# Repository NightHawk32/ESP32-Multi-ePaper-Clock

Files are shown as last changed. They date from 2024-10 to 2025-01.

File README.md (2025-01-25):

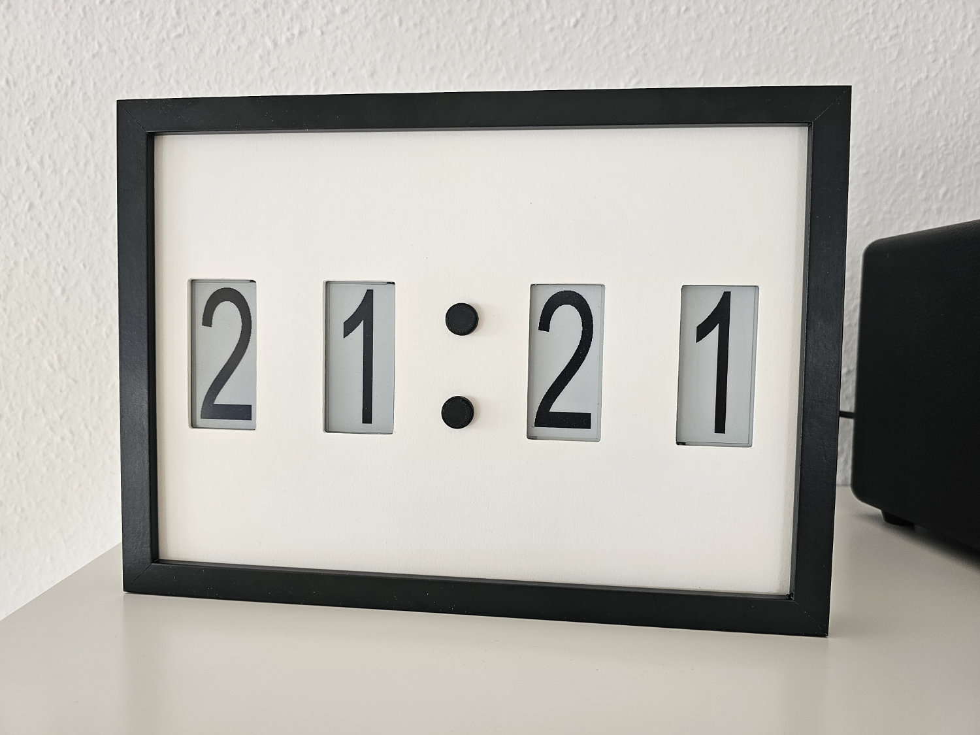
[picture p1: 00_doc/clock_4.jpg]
Clock


# Configuration

create myWifi.h in 01_src\include`` with the following content, containing your wifi credentials:

```cpp
#ifndef MYWIFI_H_
#define MYWIFI_H_

#define MY_WIFI_SSID "<ssid>"
#define MY_WIFI_PASSWORD "<wifi_password>"

#define NTP_SERVER "pool.ntp.org"

#endif
```

# Wiring Diagram
In case you need to change the pinout, the pin definitions are in `01_src\include\board.h`.
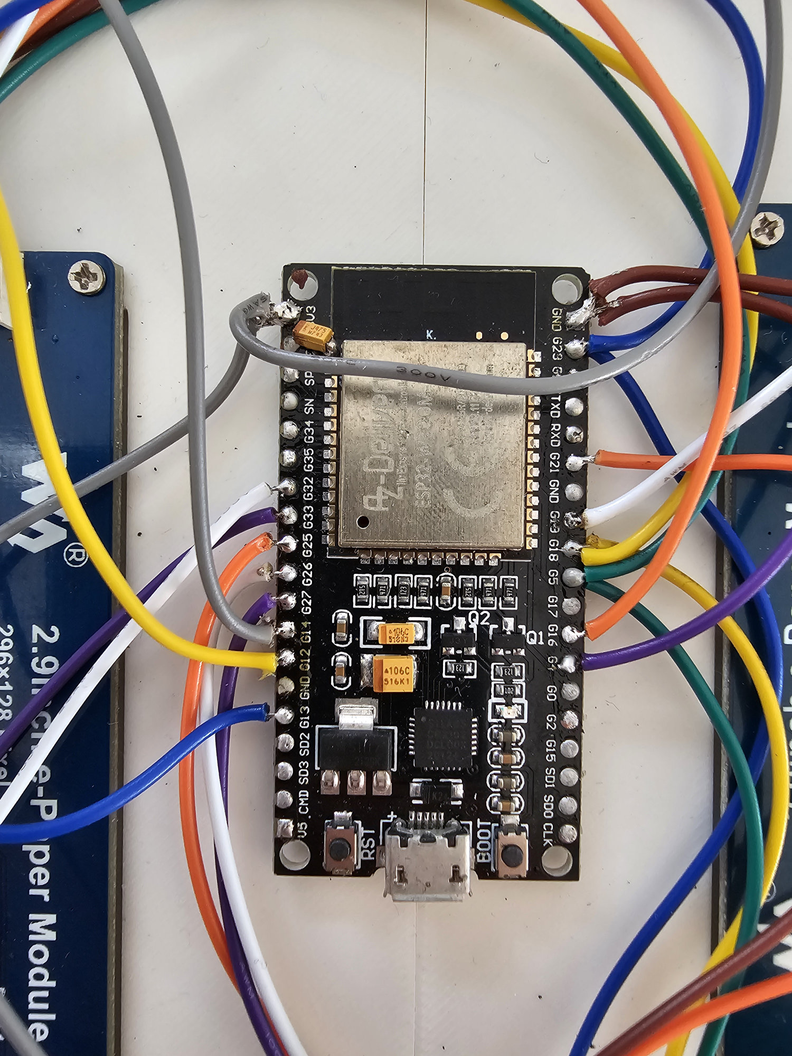
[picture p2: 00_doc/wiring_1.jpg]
Wiring Diagram

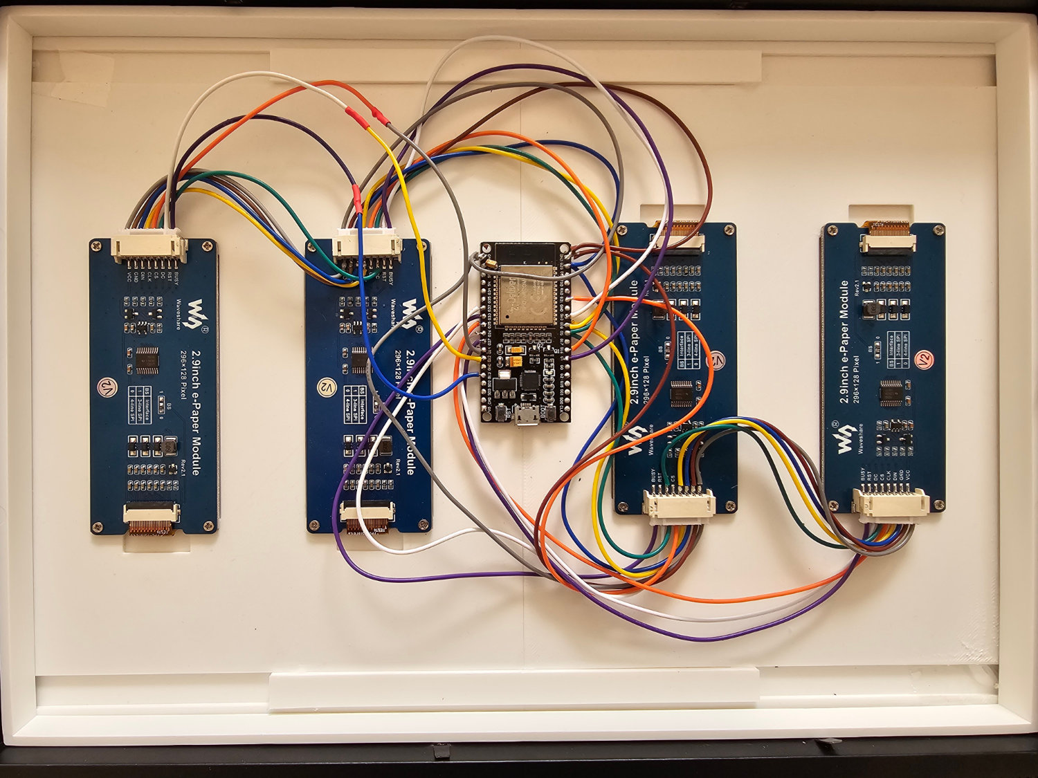
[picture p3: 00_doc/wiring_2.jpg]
Wiring Diagram


# Parts List
- picture frame 30x40 cm ([IKEA RÖDALM](https://www.ikea.com/de/de/p/roedalm-rahmen-schwarz-20548918/))
- ESP32 Dev Kit (e.g. [AZDelivery ESP32 NodeMCU](https://www.az-delivery.de/en/products/esp32-developmentboard))
- 4x Wavesahre 2.9inch e-Paper Display ([Waveshare 2.9inch e-Paper Display](https://www.waveshare.com/wiki/2.9inch_e-Paper_Module))

# 3D Printing

The 3D printing pars are available in the `02_cad` and on [Printables](https://www.printables.com/model/1162687/).

Parts:
- 2x connector (PLA)
- 2x front panel (PLA, white)
- 2x dot (PLA, black)

# Assembly
To hide the small gap between the front panels I used a big sheet of white paper and cut the display holes into it. The paper is then glued to the back of the front panel.

# Editing the Digit Font

The font file as Affinity Designer file is available in the res directory. To convert the exported images to bitmaps you may use this [tool](https://javl.github.io/image2cpp/). Th bitmaps can be found in `01_src\include\bitmaps.h`.

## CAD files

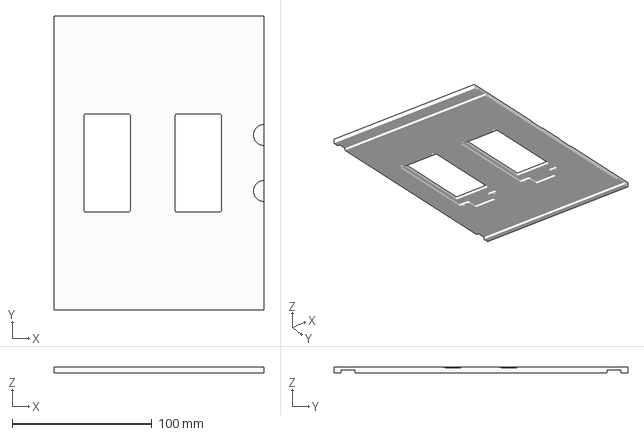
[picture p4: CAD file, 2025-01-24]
02_cad/panel_front.3mf
150.0 x 210.0 x 4.00 mm

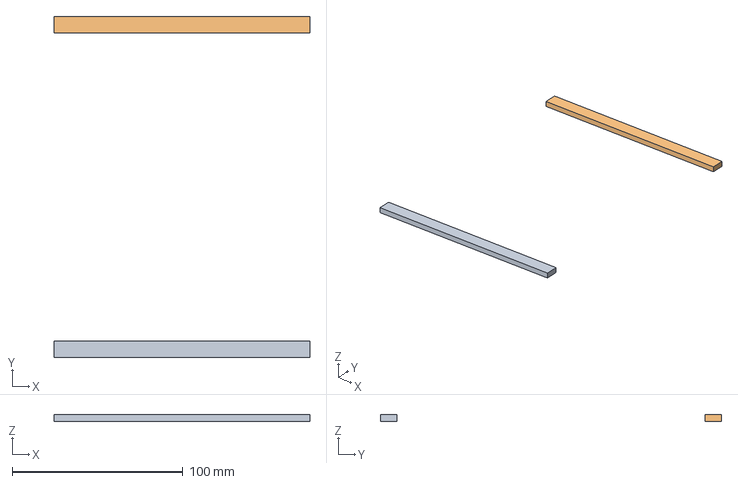
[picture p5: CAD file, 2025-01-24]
02_cad/connector.3mf
149.8 x 199.8 x 4.00 mm
Körper1
Körper2

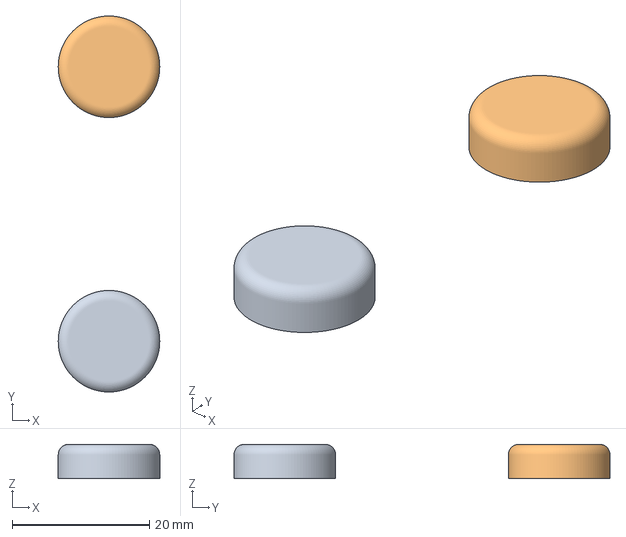
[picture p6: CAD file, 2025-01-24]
02_cad/dot.3mf
14.8 x 54.8 x 5.00 mm
Körper1
Körper2

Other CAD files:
02_cad/29_epaper_4_digit v15.f3z

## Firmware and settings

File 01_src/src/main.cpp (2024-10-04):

#include <GxEPD2_BW.h>
#include "board.h"
#include "bitmaps.h"
#include "GxEPD2_display_selection_new_style.h"
#include <U8g2_for_Adafruit_GFX.h>
#include "myWifi.h"
#include <WiFi.h>
#include <time.h>

const long  gmtOffset_sec = 3600;
const int   daylightOffset_sec = 0;

TaskHandle_t updateDisplayTaskHandle = NULL;
SemaphoreHandle_t semDisplay = NULL;

struct tm timeinfo;

U8G2_FOR_ADAFRUIT_GFX u8g2Fonts1;
U8G2_FOR_ADAFRUIT_GFX u8g2Fonts2;
U8G2_FOR_ADAFRUIT_GFX u8g2Fonts3;
U8G2_FOR_ADAFRUIT_GFX u8g2Fonts4;

const char HelloWorld[] = "Hello World!";
const char one[] = "Hello World!";

void printLocalTime(){
  struct tm timeinfo;
  if(!getLocalTime(&timeinfo)){
    Serial.println("Failed to obtain time");
    return;
  }
  Serial.println(&timeinfo, "%A, %B %d %Y %H:%M:%S");
}

void scanNetworks() {
  Serial.println("Scan start");

  // WiFi.scanNetworks will return the number of networks found.
  int n = WiFi.scanNetworks();
  Serial.println("Scan done");
  if (n == 0) {
      Serial.println("no networks found");
  } else {
      Serial.print(n);
      Serial.println(" networks found");
      Serial.println("Nr | SSID                             | RSSI | CH | Encryption");
      for (int i = 0; i < n; ++i) {
          // Print SSID and RSSI for each network found
          Serial.printf("%2d",i + 1);
          Serial.print(" | ");
          Serial.printf("%-32.32s", WiFi.SSID(i).c_str());
          Serial.print(" | ");
          Serial.printf("%4ld", WiFi.RSSI(i));
          Serial.print(" | ");
          Serial.printf("%2ld", WiFi.channel(i));
          Serial.print(" | ");
          switch (WiFi.encryptionType(i))
          {
          case WIFI_AUTH_OPEN:
              Serial.print("open");
              break;
          case WIFI_AUTH_WEP:
              Serial.print("WEP");
              break;
          case WIFI_AUTH_WPA_PSK:
              Serial.print("WPA");
              break;
          case WIFI_AUTH_WPA2_PSK:
              Serial.print("WPA2");
              break;
          case WIFI_AUTH_WPA_WPA2_PSK:
              Serial.print("WPA+WPA2");
              break;
          case WIFI_AUTH_WPA2_ENTERPRISE:
              Serial.print("WPA2-EAP");
              break;
          case WIFI_AUTH_WPA3_PSK:
              Serial.print("WPA3");
              break;
          case WIFI_AUTH_WPA2_WPA3_PSK:
              Serial.print("WPA2+WPA3");
              break;
          case WIFI_AUTH_WAPI_PSK:
              Serial.print("WAPI");
              break;
          default:
              Serial.print("unknown");
          }
          Serial.println();
          delay(10);
      }
  }
  Serial.println("");

  // Delete the scan result to free memory for code below.
  WiFi.scanDelete();
}

void setup_wifi() {
  WiFi.mode(WIFI_STA);  
  delay(10);
  WiFi.begin(MY_WIFI_SSID, MY_WIFI_PASSWORD);
  int counter = 0;
  while (WiFi.status() != WL_CONNECTED) {
    delay(500);
    if (++counter > 100) ESP.restart();
    Serial.print(".");
  }
  Serial.print("WiFi connected: ");
  Serial.println(MY_WIFI_SSID);
}

void disable_wifi(){
    WiFi.disconnect();
    WiFi.mode(WIFI_OFF);
}

void updateDisplayTask(void *pvParameters){
  while(1){
        static int d1_up_cnt = 0;
        static int d2_up_cnt = 0;
        static int d3_up_cnt = 0;
        static int d4_up_cnt = 0;

        static int min_low_prev = 99;
        static int min_high_prev = 99;
        static int hr_low_prev = 99;
        static int hr_high_prev = 99;
    if(xSemaphoreTake(semDisplay,portMAX_DELAY)){

        int min_low = timeinfo.tm_min %10;
        int min_high = timeinfo.tm_min /10;
        int hr_low = timeinfo.tm_hour %10;
        int hr_high = timeinfo.tm_hour /10;

        if(min_low != min_low_prev){
            if(d4_up_cnt >= 10){
                display4.setFullWindow();
                d4_up_cnt = 0;
            }else{
                display4.setPartialWindow(0, 0, display4.width(), display4.height());
            }                
            display4.firstPage();
            do
            {
                display4.fillScreen(GxEPD_WHITE);
                display4.drawInvertedBitmap(0, 0, epd_bitmap_allArray[min_low], 128, 296, GxEPD_BLACK);
            }
            while (display4.nextPage());
            d4_up_cnt++;
        }

        if(min_high != min_high_prev){
            if(d3_up_cnt >= 10){
                display3.setFullWindow();
                d3_up_cnt = 0;
            }else{
                display3.setPartialWindow(0, 0, display3.width(), display3.height());
            }                
            display3.firstPage();
            do
            {
                display3.fillScreen(GxEPD_WHITE);
                display3.drawInvertedBitmap(0, 0, epd_bitmap_allArray[min_high], 128, 296, GxEPD_BLACK);
            }
            while (display3.nextPage());
            d3_up_cnt++;
        }

        if(hr_low != hr_low_prev){
            if(d2_up_cnt >= 10){
                display2.setFullWindow();
                d2_up_cnt = 0;
            }else{
                display2.setPartialWindow(0, 0, display2.width(), display2.height());
            }                
            display2.firstPage();
            do
            {
                display2.fillScreen(GxEPD_WHITE);
                display2.drawInvertedBitmap(0, 0, epd_bitmap_allArray[hr_low], 128, 296, GxEPD_BLACK);
            }
            while (display2.nextPage());
            d2_up_cnt++;
        }

        if(hr_high != hr_high_prev){
            if(d1_up_cnt >= 10){
                display1.setFullWindow();
                d1_up_cnt = 0;
            }else{
                display1.setPartialWindow(0, 0, display1.width(), display1.height());
            }                
            display1.firstPage();
            do
            {
                display1.fillScreen(GxEPD_WHITE);
                display1.drawInvertedBitmap(0, 0, epd_bitmap_allArray[hr_high], 128, 296, GxEPD_BLACK);
            }
            while (display1.nextPage());
            d1_up_cnt++;
        }

        display1.hibernate();
        display2.hibernate();
        display3.hibernate();
        display4.hibernate();

        min_low_prev = min_low;
        min_high_prev = min_high;
        hr_low_prev = hr_low;
        hr_high_prev = hr_high;        
    }
  }  
}

void setup()
{
    delay(500);
    Serial.begin(115200); /* prepare for possible serial debug */

    Serial.println("Starting ....");
    delay(1000);
	
    display1.init(0, true, 2, false); // USE THIS for Waveshare boards with "clever" reset circuit, 2ms reset pulse
    display2.init(0, true, 2, false);
    display3.init(0, true, 2, false);
    display4.init(0, true, 2, false);

    display1.setRotation(2);
    display2.setRotation(2);
    display3.setRotation(0);
    display4.setRotation(0);

    display1.hibernate();
    display2.hibernate();
    display3.hibernate();
    display4.hibernate();
	Serial.println("Setup done ....");
    //scanNetworks();
    setup_wifi();
    configTzTime("CET-1CEST,M3.5.0,M10.5.0/3", NTP_SERVER);
    delay(5000);
    getLocalTime(&timeinfo);

    semDisplay = xSemaphoreCreateBinary();
    xTaskCreate(
        updateDisplayTask,     // Function name of the task
        "Update Display",  // Name of the task (e.g. for debugging)
        2048,       // Stack size (bytes)
        NULL,       // Parameter to pass
        1,          // Task priority
        &updateDisplayTaskHandle  // Assign task handle
    );  

    disable_wifi();  
}

long nextUpdate = 0;


void loop()
{
    /*if(WiFi.status() != WL_CONNECTED){
        setup_wifi();
    }*/

    if(millis() > nextUpdate){    
        if(!getLocalTime(&timeinfo)){
            Serial.println("Failed to obtain time");
        }
        Serial.println(&timeinfo, "%A, %B %d %Y %H:%M:%S");
        nextUpdate = millis() + (60-timeinfo.tm_sec)*1000;
        xSemaphoreGive(semDisplay);

        if(timeinfo.tm_min == 00){
            setup_wifi();
            configTzTime("CET-1CEST,M3.5.0,M10.5.0/3", NTP_SERVER);
            Serial.println("Re-syncing time via NTP");
            delay(5000);
            getLocalTime(&timeinfo);
            disable_wifi();
        }
  }
    
}

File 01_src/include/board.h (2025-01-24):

#ifndef BOARD_H_
#define BOARD_H_

#define PIN_EPD3_BUSY 4
#define PIN_EPD3_RST 19
#define PIN_EPD3_CS 16

#define PIN_EPD4_BUSY 13
#define PIN_EPD4_RST 12
#define PIN_EPD4_CS 14

#define PIN_EPD1_BUSY 27
#define PIN_EPD1_RST 26
#define PIN_EPD1_CS 25

#define PIN_EPD2_BUSY 33
#define PIN_EPD2_RST 32
#define PIN_EPD2_CS 21

#define PIN_EPD_DC 5
//#define PIN_EPD_CLK 1
//#define PIN_EPD_MOSI 10

#define PIN_SDA D4
#define PIN_SCL D5

#endif

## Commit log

2024-10-02 fixed display update counter
    [main.cpp]
2025-01-24 updated pin mapping
2025-01-24 added some more information, restructured repo
    [29_epaper_4_digit v15.f3z, connector.3mf, dot.3mf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]
